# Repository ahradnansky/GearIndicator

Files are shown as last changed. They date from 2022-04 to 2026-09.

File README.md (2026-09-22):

# GearIndicator

Gear Indicator for Kawasaki and Suzuki bikes using communication with ECU over ISO9141 / K-Bus protocol

This project I implemented couple of years ago. We bought Kawasaki Z750 that time and needed to have gear indication
which apparently Kawasaki didn't have installed. About 30 of these were installed on different Kawasaki an Suzuki bikes
in following years. Just dont want this project to throw away and forget. Maybe someone will like it.

## Resources

Project has hardware and software part. Content of Resources directory:

### &emsp;__Eagle

&emsp;Hardware scheme and PCB created in CadSoft Eagle (Autodek Eagle now).
&emsp;Indicator has 2 PCBs. DISP - PCB with 7 segment display and Controller. PWR - PCB with voltage regulator and ISO9141 interface IC.

### &emsp;__HWcomponents

&emsp;Datasheets of all HW components used.

### &emsp;__Manuals

&emsp;We have created couple of installation manuals for Kawasaki and Suzuki bikes. Existing PDFs are here.

### &emsp;__SketchUp

&emsp;3D model of the final product. Prepared to be placed to the potting box. Final product with soldered cable was placed into potting box (type and data in _HWcomponents folder).
&emsp;Then Araldite expoxy was used for potting. Here you will find PCB 3D model as well as 3D model of the completed device.

# Source code

&emsp;Source code in C. Design is based on ATmega328p controller. Atmel Studio (Microchip Studio now) was used as a development IDE at the begining. Later transfeter to PlatformIO - as it is now.

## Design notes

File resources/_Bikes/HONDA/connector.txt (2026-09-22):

HONDA CT - DLC PINOUT (female)
 ---------
|  1 | 2  |-
|            | tab
|  3 | 4  |-
 ---------

1-Brown > SCS (can jumper to Ground to obtain error codes(not tested))
2-Green > Ground (0V)
3-Black/white > Batt (+12V)
4-Orange/White > K-line

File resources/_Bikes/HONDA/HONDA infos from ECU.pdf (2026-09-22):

# CTX-OBD Using a Raspberry-Pi to extract information from a Honda CTX-700

ECU.

February 2016

Here is the Raspberry-Pi mounted on the bike:

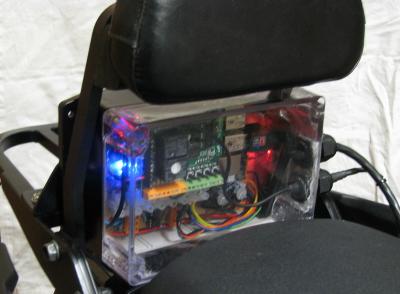
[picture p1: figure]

The data is shown on a character display on the dash. It contains the following information:

Top row: gear position, coolant temp, instantaneous fuel economy (km/litre), fuel in tank
Bottom row: % of chain oiler cycle time, average fuel economy, km to empty.

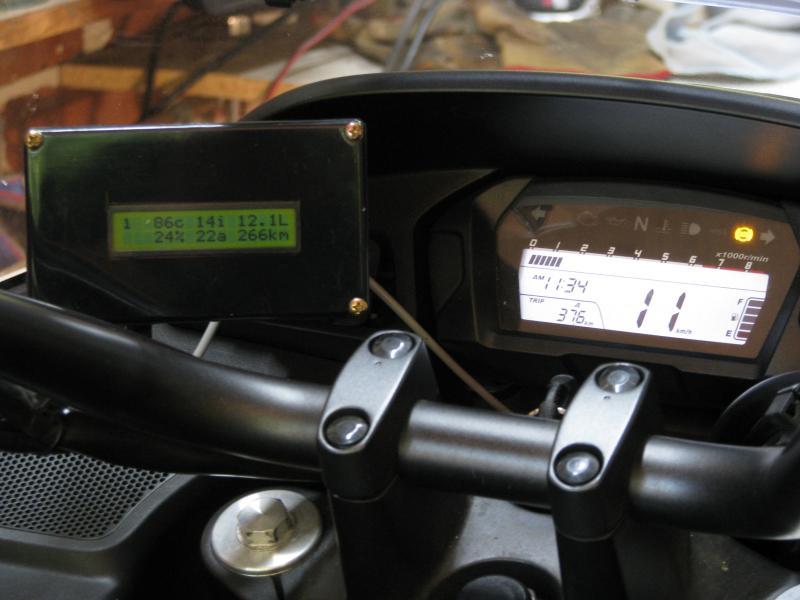
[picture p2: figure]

There is a detailed web interface that can be accessed via a smartphone:

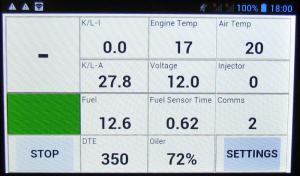
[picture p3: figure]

This document was written to help others to build a system to communicate with the ECU on Honda motorcycles. The vast majority of information here has been obtained from contributors on the pgmfi.org forum. That forum has been “down” for months, so the information is not accessible. Hence this document. Note: Feb 2016 – pgmfi.org is back up!

The key steps to extract information from the ECU are:

1. Make a cable to connect to the ECU diagnostics socket

2. Make an interface board to isolate the 12V bike signals from the 5V computer comms
3. Set up serial communications at 10400baud. This is a non-standard baud rate, so you can’t use a normal USB to serial adapter, and you can’t use a standard automotive ELM327-based unit because the ELM unit calculates the checksum differently and adds it automatically whether you want it to or not.
4. Use the correct message protocol. Honda does not use the standard ISO-9141-2 protocol.
5. Use the correct initialisation sequence. Honda does not use the standard ISO initialisation sequence (another reason not to use an ELM unit)
6. Determine where the data you are looking for is located in the ECU memory. There are a few standard locations, but you may have to proceed to step 7 to test other locations if the standard ones don’t work.
7. Write a program for your computer/Arduino/whatever to get the data and do with it what you will.
8. Package it all into something that fits on your bike.

My setup was based on a Raspberry-Pi model B+ with a PiFace2 I/O board running Raspian. I used a PiFace board because I wanted I/O for driving various things on the bike eg: an auto chain oiler. However, I also used it for pulling the K-line low (see section 5 below). You could use some other method for this function, but it was convenient for me to use one of the PiFace’s relays.

The information flows in my system are quite complex:

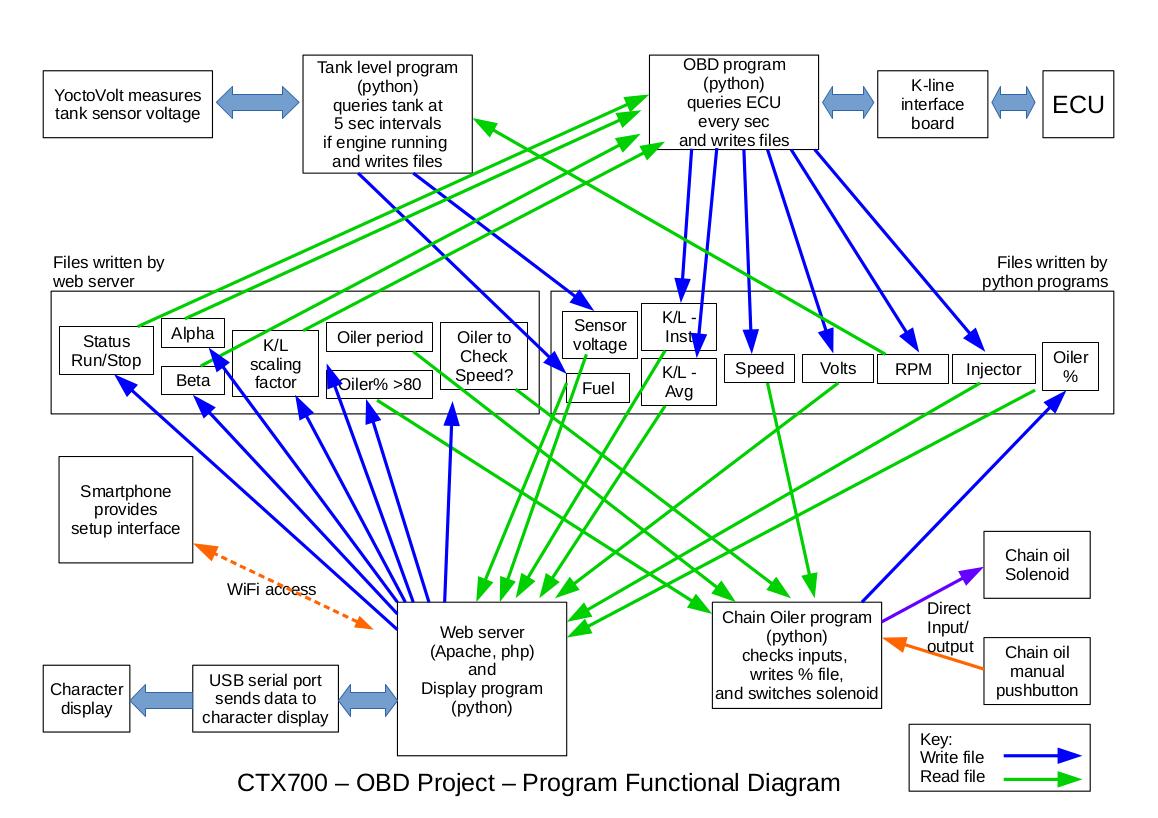
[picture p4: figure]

Going through these items one by one:

## 1. Make a cable

You need to locate the socket on your bike. The CTX socket is a red 4-pin unit near the battery. The connections are 12V, earth, bi-directional K-line and a reset line. You need only the first three to talk to the ECU. Check your manual for the wire colours. The CTX uses a Sumitomo HM090 connector. The connector on the bike looks like this:

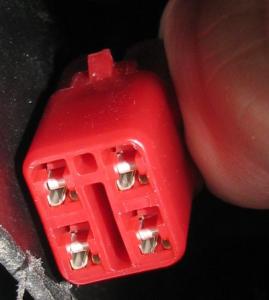
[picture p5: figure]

## 2. Make an Interface Board

I made the following board:

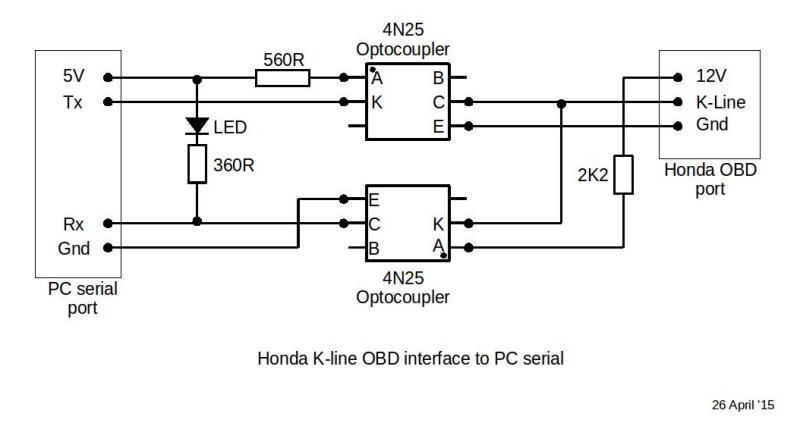
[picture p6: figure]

The K-line rides high (12V) at rest.

I used the above design incorporating optocouplers so that the bike12V was completely isolated from the computer serial adapter. It is possible to use other transistor-based circuits, but you don’t get the same level of isolation.

## 3. Set up Serial Comms

I used a FT232RL USB to serial converter, because it has a base frequency which is able to be scaled down to the 10400baud needed. When plugged into the USB port on the Rpi, it comes up as /dev/ttyUSB0.

To configure the port for 10400baud:

#!/bin/bash

setserial -v /dev/ttyUSB0 spd_cust divisor 2307

This sets the port so that, when you use a program (eg Python) to specify 38400baud for the port, it goes to the custom speed instead of 38400. The port settings are 8 bits, no parity, one stop bit.

To get the adapter to work properly on a R-Pi, you need to add the following in the /boot/cmdline.txt file :

dwc_otg.speed=1

## 4. Use the Correct Message Protocol

Basically the ECU simply responds to requests for information. It doesn’t care if the response is not heard.

A typical request is of the form:

72 07 72 11 00 14 F0 (in hexadecimal)

72: the destination code (I think?)

07: the number of characters in the message including the checksum

72: the type of query (“give me data from memory?”)

11: the data table number

00: the starting register within data table 11

14: the finishing register within data table 11

F0: the checksum

The ECU will respond with a similar format:

02 1A 72 11 00 XX XX XX …XX YY

02: the destination code (I think?)

1A: the number of characters in the message (in this case 26 decimal)

72: the type of query (“data from memory?”)

11: the data table number

00: the starting register

XX: the data

YY: the checksum

The checksum is calculated differently to the ISO OBDII protocol. It goes like this:

Sum all the values of the characters together, and take that value from 100 (hex). If the sum is greater than 100 hex, just use the last two characters (in hex).

So, the request message above (in hex) would be:

0x72 + 0x07 + 0x72 + 0x11 + 0x00 + 0x14 = 0x110

Use only the last two characters, 0x10

0x100 – 0x10 = 0xF0 = the checksum F0

The response checksum is calculated similarly.

There are other query types (the third character in the request sequence). The ones I know to exist are 71, 72, 73 and 74. Code 71 requests all off the table data, rather than a subset:

72 05 71 00 18 requests all of the data in table 00

I don’t know what a code 73 or 74 request does.

## 5. Use the correct Initialisation Sequence

The ECU will not respond until it has received the correct initialisation sequence. I used this:

- Pull the K-line low for 70msec
- Return the K-line to the high state for 120msec
- Send “Wakeup” message: FE 04 FF FF. No response is expected
- Wait 200msec
- Send “Initialise” message: 72 05 00 F0 99
- The ECU should respond with: 02 04 00 FA

That’s it. You can then send requests and the ECU should respond with the data requested. The communications needs to be “kept alive”, however. That means that if the ECU hasn’t received a request within a certain time it goes back to sleep and needs to be initialised again. I think the time is around 3 sec.

Note that I haven’t tested the above times to see what the limits are. All I know is that they work for me and my system.

How do you pull the K-line low? I used a relay driven by the R-Pi. It simply shorted the K-line and ground terminals on the interface board. It doesn’t have to be a relay. If you’re using a “soft serial” where you can directly control the Tx line, you can simply pull that low, and the interface board will pull the K-line low.

## 6. Determine where the data is located

I tabulated the information obtained from a few guys working on this project at pgmfi.org . The data for the small selection of bikes shows that the critical information is held in only a few data table, and some of these tables are duplicated (don’t know why). The most frequently used tables are 00, 10 and 60, 11 and 61, so those the re best places to start. Refer to the “Honda Data Tables.pdf” document:

Honda-data-tables

The document shows the contents of the various tables on the bikes tested, and it shows how to calculate the real life data from the values that come from the ECU.

The data comes in single or double bytes – double bytes are used for data that needs more precision or has a high value (eg: engine speed)

If these data tables don’t work for you, you’ll have to write a program to “scan” through the various table numbers to see where the data exists. The ECU will simply reflect your query back at you if the table doesn’t exist.

## 7. Write a program

Writing a program is up to you. I used Python running under Raspbian. You need a program that handles serial comms (obviously). You will have to be able to handle the following:

- Initialisation
- sending/receiving data normally
- determining if the received data is valid (checksum)
- handling comms errors (the bike is an electrically noisy place)
- keeping the ECU awake, and waking it if it goes to sleep

Receiving data is tricky. Because all the comms come on one line, the serial adapter receives all the data it sends, as well as the responses from the ECU. In addition, the ECU doesn’t necessarily respond immediately – it may be busy doing something else, so you have to wait until you have received the full response. In addition, the program has to ignore anything that comes back from the initialisation sequence.

I used the following process:

1. clear send buffer
2. send message
3. clear receive buffer
4. loop through a single character receive program until a response of the required length has been received (I know how long the response should be)
5. if no new characters are received within x cycles, exit the loop
6. determine if the message is valid – if not, don’t process, and try sending again. If a valid message is not received in x tries, reinitialise the comms.
7. process the valid response

## 8. Package it

This is what I did – it may give you ideas. The R-Pi controls the following:

- The OBD communication
- The auto chain oiler solenoid
- The fuel tank level reporting
- The web server which provides the user interface

My R-Pi was set up as a wireless hotspot so the user interface (an old Medion smartphone) could be used without wires. In addition, it means that any program changes can be done without connecting a keyboard and monitor to the computer.

Here’s the assembly on the test bench:

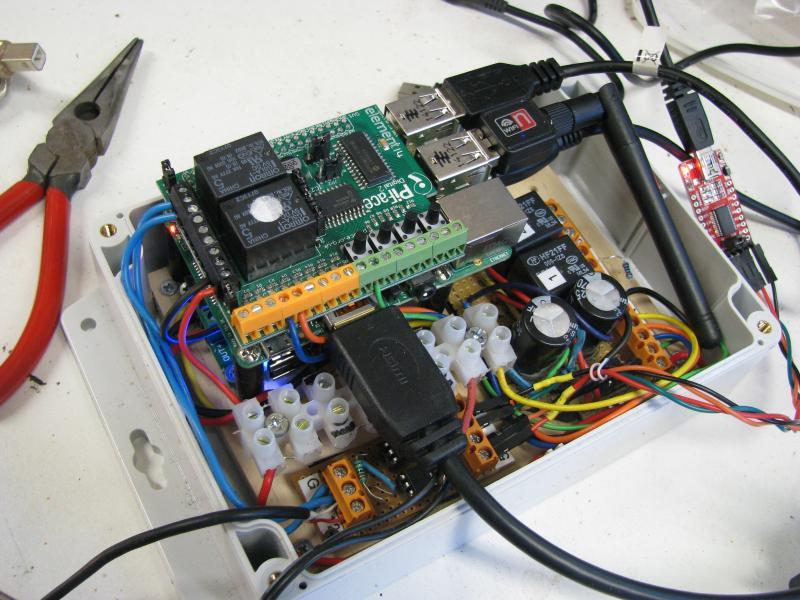
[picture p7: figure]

Here’s the wiring diagram:

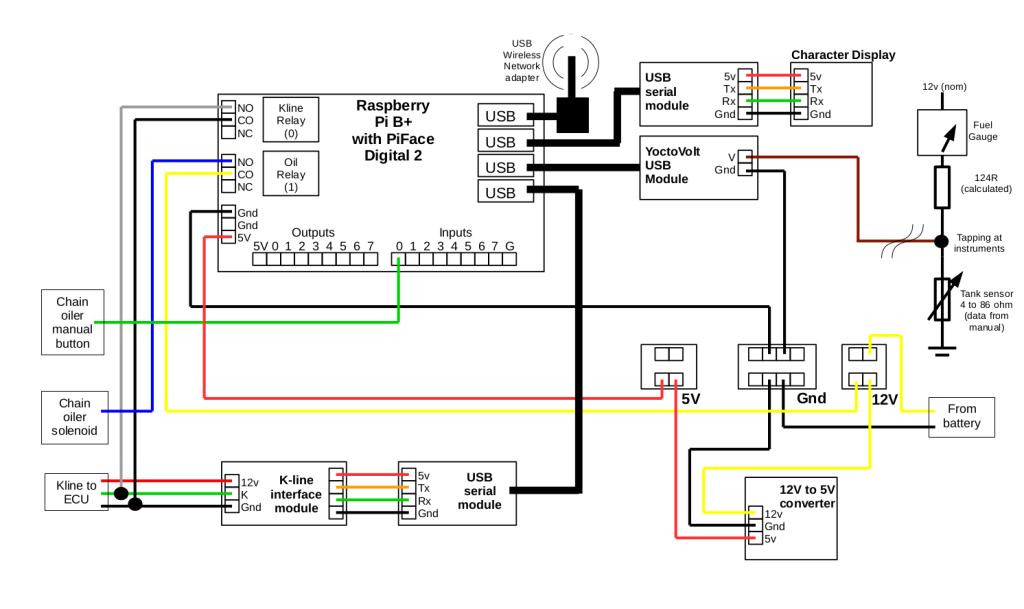
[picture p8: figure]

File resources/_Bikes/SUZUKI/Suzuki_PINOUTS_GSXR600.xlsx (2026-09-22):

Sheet: GSXR600
 |  | 2001-2003 GSXR600 |  |  | 2004-2005 GSXR600 |  |  | 2006-2007 GSXR600 |  |  | 2008-2011 GSXR600
PIN | COLOUR | FUNCTION | PIN | COLOUR | FUNCTION | PIN | COLOUR | FUNCTION | PIN | COLOUR | FUNCTION
1 | WHITE/BLUE | COIL 1 | 1 | W/B | STVA signal (STVA. 2A) | 1 | W/B | STVA signal (STVA. 2A) | 1 | B/R | EXCVA power (MO+)
2 | BLACK | COIL 2 | 2 | P/W | STVA signal (STVA. 1A) | 2 | P/W | STVA signal (STVA. 1A) | 2 | P | Speed sensor signal
3 | YELLOW | COIL 3 | 3 |  |  | 3 | R/B | EXCVA power (MO-) | 3 | W/B | STVA signal (STVA. 2A)
4 | GRAY/WHITE | INJ 4 | 4 |  |  | 4 | B/R | EXCVA power (MO+) | 4 | P/W | STVA signal (STVA. 1A)
5 | GRAY/BLACK | INJ 3 | 5 |  |  | 5 | Y | EXCVA position sensor (MPS) | 5 | B/W
6 | GRAY/YELLOW | INJ 2 | 6 | B/G | Serial data for speedometer | 6 | B/G | Serial data for speedometer | 6 | P/B | TP sensor signal (TP)
7 | GRAY/RED | INJ 1 | 7 |  | TX | 7 | W | TX | 7 | R | Power source for sensors (VCC)
8 |  |  | 8 | P/B | TP sensor signal (TP) | 8 | P/B | TP sensor signal (TP) | 8 | B/Y | CMP sensor signal (CMP+)
9 | YELLOW/BLACK | FUEL PUMP | 9 | G/B | IAP sensor signal (IAP) | 9 | G/B | IAP sensor signal (IAP) | 9 | G/W | CKP sensor signal (CKP+)
10 | GREEN | COIL 4 | 10 | B/BL | ECT sensor signal (ECT) | 10 | B/BL | ECT sensor signal (ECT) | 10 | R/BL | Power source for back-up
11 |  |  | 11 | R | Power source for sensors (VCC) | 11 | R | Power source for sensors (VCC) | 11 | Y/BL | Tachometer
12 |  |  | 12 |  | Blank | 12 | W/G | HO2 sensor signal (OX) [E02,E19,E24] | 12 | O/G | Power source
13 |  |  | 13 | B/Y | CMP sensor signal (CMP+) | 13 | B/Y | CMP sensor signal (CMP+) | 13 | R/B | EXCVA power (MO-)
14 |  |  | 14 | G/W | CKP sensor signal (CKP+) | 14 | G/W | CKP sensor signal (CKP+) | 14 | Y | EXCVA position sensor (MPS)
15 | BLUE/RED | MAP SELECT | 15 |  | Blank | 15 | Bl/R | Blank | 15 | BL/Y
16 | BLUE/YELLOW | COS2 | 16 | R/BL | Power source for back-up | 16 | R/BL | Power source for back-up | 16 | BL/G
17 | ORANGE/WHITE | SWITCHED 12V | 17 | O/G | Power source | 17 | O/G | Power source | 17
18 | BLACK/WHITE | GROUND | 18 | G | STVA signal (STVA. 2B) | 18 | G | STVA signal (STVA. 2B) | 18 | Y/W | STP sensor signal (STP)
19 | BLACK/YELLOW | STARTER RELAY INPUT | 19 | B/LG | STVA signal (STVA. 1B) | 19 | B/LG | STVA signal (STVA. 1B) | 19 | G/B | IAP sensor signal (IAP)
20 | BLUE | NEUTRAL INPUT | 20 | Y/W | STP sensor signal (STP) | 20 | Y/W | STP sensor signal (STP) | 20 | G/Y | AP sensor signal (AP)
21 | BLACK/BROWN | GROUND | 21 | O/Y | Ignition switch signal [E03,E28,E33] | 21 | Br/Y | Ignition switch signal [E03,E28,E33] | 21 | G/BL | CKP sensor signal (CKPS-)
22 | WHITE/RED | DEALER MODE SWITCH | 22 | B | TO sensor signal (TOS) | 22 | B | TO sensor signal (TOS) | 22 | P | GP switch signal (GP)
23 | BLUE/WHITE | COV1 | 23 | P | GP switch signal (GP) | 23 | P | GP switch signal (GP) | 23 | B/G | Serial data for speedometer
24 | BLUE/BLACK | COV2 | 24 |  | RX | 24 | DGR | RX | 24 | Y/R | Power source for fuel injector (VM)
25 | BLUE/GREEN | COV3 | 25 |  | Blank | 25 |  | Reset | 25 | BR | Steering Damper solenoid (SSO-)
26 | BLACK/WHITE | GROUND | 26 | G/Y | AP sensor signal (AP) | 26 | G/Y | AP sensor signal (AP) | 26 | W | Steering Damper solenoid (SSO+)
27 | BLACK/WHITE | GROUND | 27 | DG | IAT sensor signal (IAT) | 27 | DG | IAT sensor signal (IAT) | 27 | G | STVA signal (STVA. 2B)
28 | YELLOW/GREEN | STARTER RELAY POWER | 28 |  | FWE | 28 |  | FWE | 28 | B/LG | STVA signal (STVA. 1B)
29 |  |  | 29 | B/BR | Sensors ground (E2) | 29 | B/BR | Sensors ground (E2) | 29
30 |  |  | 30 | BR | CMP sensor signal (CMP-) | 30 | B/BR | EXCVA & HO2 sensor control selector [For E02,E19] | 30
31 | BROWN | PIN 5 2ND ECU | 31 | G/BL | CKP sensor signal (CKP-) | 31 | O/BL | CKP sensor signal (CKP-) | 31 | B | TO sensor signal (TOS)
32 |  |  | 32 | GR | Serial data for self-diagnosis (K-Line) | 32 | GR | Serial data for self-diagnosis (K-Line) | 32 | B/BL | ECT sensor signal (ECT)
33 |  |  | 33 | Y/R | Power source for fuel injector (VM) | 33 | Y/R | Power source for fuel injector (VM) | 33 | DG | IAT sensor signal (IAT)
34 |  |  | 34 | B/W | ECM ground (E1) | 34 | B/W | ECM ground (E1) | 34 | W/G | HO2 sensor (HO2S)
35 | BLACK/WHITE | GROUND | 35 | BL/Y |  | 35 |  |  | 35 | B/BR | Sensors ground (E2)
36 | WHITE | CRANK + | 36 | BL/R |  | 36 |  |  | 36 | B/W | ECM ground (E1)
37 | BLACK/YELLOW | CAM + | 37 | Y/BL | Tachometer | 37 | BL/Y |  | 37 | G | ISC valve signal (ISC 2A)
38 |  |  | 38 |  |  | 38 | Y/BL | Tachometer | 38 | Y | ISC valve signal (ISC 1B)
39 |  |  | 39 | Y/B | Fuel pump relay (FP Relay) | 39 | Y/B | Fuel pump relay (FP Relay) | 39 | BL | ISC valve signal (ISC 1A)
40 |  |  | 40 | Y/G | Starter relay | 40 | R/Y | Immobilizer communication [E02,E19,E24] | 40 | Y/B | Fuel pump relay (FP Relay)
41 |  |  | 41 | GR/R | Primary fuel injector #4 (#41) | 41 | W/B | HO2 Sensor Heater (OXH) [For E02,E19] | 41 | W/B | HO2 sensor heater (HO2H)
42 | YELLOW/RED | FUEL 12V | 42 | GR/Y | Primary fuel injector #3 (#31) | 42 | Y/G | Starter relay | 42 | G/R | Cooling fan relay (FAR)
43 | GREEN/WHITE | CRANK - | 43 | GR/B | Primary fuel injector #2 (#21) | 43 | O/R | Cooling fan relay (FAR) | 43 | GR/R | Primary fuel injector #4 (#41)
44 | BROWN | CAM - | 44 | GR/W | Primary fuel injector #1 (#11) | 44 | W/G | PAIR control solenoid valve (PAIR) | 44 | GR/Y | Primary fuel injector #3 (#31)
45 |  |  | 45 | Y | Ignition coil #3 | 45 | GR/R | Primary fuel injector #4 (#41) | 45 | GR/B | Primary fuel injector #2 (#21)
46 |  |  | 46 | B | Ignition coil #2 | 46 | GR/Y | Primary fuel injector #3 (#31) | 46 | GR/W | Primary fuel injector #1 (#11)
47 |  |  | 47 | W/BL | Ignition coil #1 | 47 | GR/B | Primary fuel injector #2 (#21) | 47 | B | Ignition coil #2
48 | RED | VCC | 48 | BL/G |  | 48 | GR/W | Primary fuel injector #1 (#11) | 48 | W/BL | Ignition coil #1
49 | PINK/BLACK | TPS | 49 | BL/B |  | 49 | Y | Ignition coil #3 | 49 | BR | ISC valve signal (ISC 2B)
50 | DARK GREEN | AIR TEMP | 50 | B/W |  | 50 | B | Ignition coil #2 | 50 | O/R | Driving mode switch 2 (DMS2)
51 | BLACK/BLUE | WATER TEMP | 51 | W/R |  | 51 | W/BL | Ignition coil #1 | 51 | BL/B
52 | GREEN/YELLOW | AP SENSOR | 52 | B/W |  | 52 |  |  | 52 | BL/W
53 |  |  | 53 | BL |  | 53 |  |  | 53 | R/Y | Immobilizer communication [E2,E19,E24]
54 | BLACK/BROWN | SENSOR GROUND | 54 | BL | Neutral switch | 54 | BL/G |  | 54 | Y/G | Starter relay
55 | YELLOW/BLU | TACH OUT | 55 | B/Y | Clutch position switch | 55 | BL/B |  | 55 | W/G | PAIR control solenoid valve (PAIR)
56 | BLACK/GREEN | tech | 56 | W/G | PAIR control solenoid valve (PAIR) | 56 | BL/W |  | 56 | LG/BL | Secondary fuel injector #4 (#42)
57 | PINK | GEAR POSITION | 57 | BLACK/WHITE | Ground | 57 | O/BL | Immobilizer communication [E02,E19,E24] | 57 | LG/G | Secondary fuel injector #3 (#32)
58 | GREEN/BLACK | IAPS | 58 | BLACK/WHITE | Ground | 58 | B/BR | Map Switch [Mode Select Switch] | 58 | LG/W | Secondary fuel injector #2 (#22)
59 | BLACK | TIP OVER | 59 | BLACK/WHITE | Ground for ignition system | 59 | BL | Neutral switch | 59 | LG | Secondary fuel injector #1 (#12)
60 | ORANGE/YELLOW | ANTI THEFT | 60 | GREEN | Ignition coil #4 | 60 | B/Y | Clutch position switch | 60 | Y | Ignition coil #3
 | SECONDARY THROTTLE ECU |  |  |  | YOSHI CONNECTOR | 61 | LG/BL | Secondary fuel injector #4 (#42) | 61 |  | EVAP system purge control solenoid [E33]
1 | LIGHT BLUE | ST PS +5V | 1 |  |  | 62 | LG/G | Secondary fuel injector #3 (#32) | 62 | GR | Serial data for self-diagnosis
2 | BLACK | ST PS GND | 2 | R | PIN 11 (VCC) | 63 | LG/W | Secondary fuel injector #2 (#22) | 63 | O/BL | Driving mode switch 1 (DMS1)
3 | BLACK/GRAY | GND | 3 | BL/Y | PIN 35 | 64 | LG | Secondary fuel injector #1 (#12) | 64 | BR/Y | Immobilizer indicator light [E02,E19,E24]
4 | ORANGE/WHITE | 12V | 4 | BL/R | PIN 36 | 65 | W/R | Dealer Mode | 65 | O/BL | Immobilizer communication [E2,E19,E24]
5 | BROWN | PIN31 ECU | 5 | BL/G | PIN 48 | 66 | B/W | General ground (E01) | 66 | B/W
6 | YELLOW | ST PS INPUT | 6 | BL/B | PIN 49 | 67 | B/W | Ground for ignition system (E03) | 67 | BL | Neutral switch
7 | RED/BLACK | M- | 7 | BL/W | PIN 50 | 68 | G | Ignition coil #4 | 68 | B/W | General ground (E1)
8 | YELLOW/BLACK | M+ | 8 | B/BR | PIN 29 |  | SDS |  | 69 | B/Y | Clutch position switch
 |  |  |  |  |  | 1 | B/W | PIN 34 GND | 70 | W/R | Mode select switch
 |  |  |  |  |  | 2 | GR | PIN 32 (KLINE) | 71 | B/W | Ground for ignition system
 |  |  |  |  |  | 3 | DGR | PIN 24 (RX) | 72 | G | Ignition coil #4
 |  |  |  |  |  | 4 | W/R | PIN 56 Dealer Mode |  | SDS
 |  |  |  |  |  | 5 | W | PIN 7 (TX) | 1 | B/W | PIN 36
 |  |  |  |  |  | 6 | O/G | PIN 17 (PWR SOURCE) +12V | 2 | GR | PIN 62 (KLINE)
 |  |  |  |  |  |  |  | YOSHI CONNECTOR | 3
 |  |  |  |  |  | 1 |  |  | 4 | W/R | PIN 70
 |  |  |  |  |  | 2 | R | PIN 11 (VCC) | 5
 |  |  |  |  |  | 3 | BL/Y | PIN 37 | 6 | O/G | PIN 12 (PWR SOURCE)
 |  |  |  |  |  | 4 | BL/R | PIN 15 |  |  | YOSHI CONNECTOR
 |  |  |  |  |  | 5 | BL/G | PIN 54 | 1
 |  |  |  |  |  | 6 | BL/B | PIN 55 | 2 | R | PIN 7 (VCC)
 |  |  |  |  |  | 7 | BL/W | PIN 56 | 3 | BL/Y | PIN 15
 |  |  |  |  |  | 8 | B/BR | PIN 29 | 4
 |  |  |  |  |  |  |  |  | 5 | BL/G | PIN 16
 |  |  |  |  |  |  |  |  | 6 | BL/B | PIN 51
 |  |  |  |  |  |  |  |  | 7 | BL/W | PIN 52
 |  |  |  |  |  |  |  |  | 8 | B/BR | PIN 35
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

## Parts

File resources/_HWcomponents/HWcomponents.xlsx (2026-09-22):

Component | Type | Pcs | unit
Controller | ATMEGA328P | 1 | off
Cer. resonator | ZTTCR8.00MG | 1 | off
Resistor | 470R, 0603, 0.25W | 8 | off
Capacitor | Tantal 10u/25V Case A | 1 | off
Capacitor | Tantal 22u/10V Case A | 1 | off
Capacitor | 100n, 50V, 1206 | 1 | off
Bus Driver | L9637 | 1 | off
Volt. Regulator | AP1117E50 | 1 | off
Resitor | 560R, 1206, 0.25W | 1 | off
Diode | DIODE S1M, 1A, 1kV | 1 | off
7-segment LED | 7SEG SA56-11LSRWA (RED) | 1 | off
Potting box | HAMMOND 1596B102-10 ENCLOSURE, POTTING BOX, ABS, BLACK | 1 | off
Cable | Helukabel TRONIC (LiYY) 18002, 3 x 0.14mm2 | 2 | m
Potting expoxy | Araldite2020 (clear epoxy adhesive system) | 9 | ml

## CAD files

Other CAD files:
resources/_SketchUp/GearIndicator_pcb.skp
resources/_SketchUp/GearIndicator_pcb_model.skp

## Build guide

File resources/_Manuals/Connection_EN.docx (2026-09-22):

Gear Indicator connection to a Kawasaki service connector

1. Find service connector

99% Kawasaki bikes have service connector under the passenger seat. Type of the connector or its shape and color can be different in comparison with the one on the photo (Z750 -2008). Common feature of the connector: it is possible to push 4 into it.

2. Remove the connector protector

On the top of service connector is the protector. Remove it and save it for future use if necessary.

3. Connection

Connect indicator pins into service connector as displayed on the photo below.

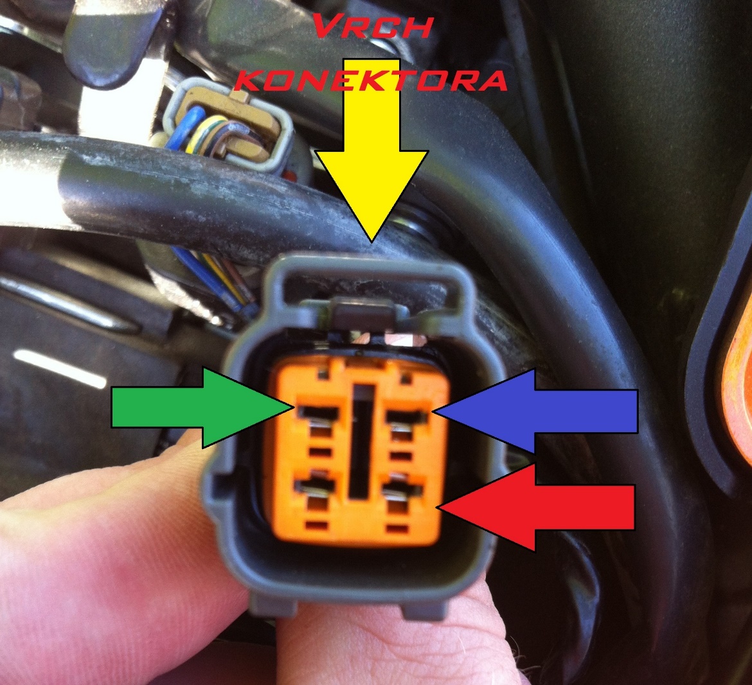
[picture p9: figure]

TOP OF THE CONNECTOR

KBUS`

GND

+12V

4. Proper insulation

After correct connection of all pins into service connector ii necessary to proper insulate everything by PVC tape to avoid shortcut or contact with water.

Note:

In case of accidental short cut during the installation the protecting fuse of the service connector can be blown. It is recommended to lead the cable smoothly without sharp angles and avoid contact with hot parts of the bike’s engine.

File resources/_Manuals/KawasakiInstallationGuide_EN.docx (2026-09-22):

Gear indication installation guide for Kawasaki bikes

1. Turn off ignition to prevent accidental protecting fuse blow during installation. (Better scenario would be additional work to change the fuse).
2. Install the indicator to a suitable place Select suitable place for installation to be visible during riding the bike. Ideal place is just beside the speedometer on the smooth plastic or metallic surface. Use degreasing agent to properly clean the surface. Remove the foil from the adhesive tape at the bottom of the indicator and place it to a desired location. Press and hold for about 10s (according to recommendation of 3M double-sided adhesive tape manufacturer).
3. Find the service (diagnostic) connector

99% Kawasaki bikes have service connector under the passenger seat. Connector color can be various – grey, black, or transparent but it is always 4-pin connector.

4. Fix the indicator cable Indicator cable should be routed together with other bike cables up to the service connector. Don’t stretch the cable nor do sharp bends. Keep minimum radius 20mm. In case of installation to handlebars or any other movable part allow free cable move. Fix cable at multiple places by using plastic ties and route it up to service connector.

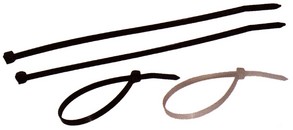
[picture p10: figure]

Avoid cable contact with hot parts of the engine to prevent its damage by heat.

5. Remove service connector protector

Service connector can be equipped by protector. Remove it and save in case the indicator will be uninstalled in the future. The protector can look like this:

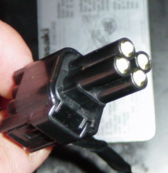
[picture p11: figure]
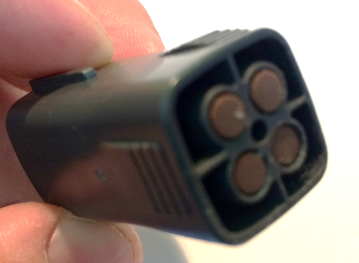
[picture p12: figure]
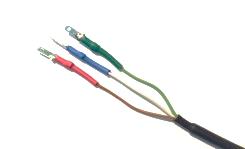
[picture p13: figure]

6. Connect indicator cable to connector

Cable is ended by 3 colored wires – red, blue and green. Connect these wires as displayed on the picture below:

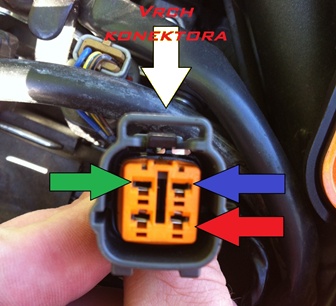
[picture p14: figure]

7. Turn-on ignition Indicator will show welcome message “LEtS ridE“ and consequently displays numbers from 0 to 6 and back 6 to 0. Then indicator starts to communicate to bike control unit (ECU). In case of correct installation and neutral gear set (even without running engine) should indicator show ‘0’ (neutral) or ‘-‘.

In case indicator showing ‘-‘ character together with ‘.’

it means indicator is not communicating to ECU. Check the connection again.

8. Insulate and protect the connector with PVC tape

Turn-off ignition again. Insulate the connector by using PVC tape and fix wires inside the connector properly to avoid disconnection by vibrations. PVC tape also protects connector against water.

„ShiftLight“ function setup – RPM over limit indication

WARNING !

Pre-condition for the setup of this function is fully functional gear indication on your bike. If your gear indication works correctly, you can start „ShiftLight“ function setup.

Before the setup it is recommended to heat-up the engine to operation temperature to avoid negative impact of high RPM on the cold engine.

1. Turn-off ignition.
2. Disconnect green wire from the service connector. Rest of wires (red and blue) leave connected.
3. Connect Green wire to the ground (- pole). Ideally connect Green and Blue wires together at the point of Blue wire connection to service connector. (It is enough to connect metal part of Green wire metal part with Blue wire metal part and hold it by hand).
4. Turn-on ignition. Indicator will show “LEtS rIdE 1-2-3-4-5-6-5-4-2-1”. Wait 2-3 seconds until indicator shows ‘P’. That indicates that ShiftLight function setup mode is active.
5. Turn-off ignition.
6. Connect Green wire back to service connector.

CONNECTOR TOP

7. Turn-on ignition and start the engine immediately. Wait until indicator shows ‘P’. It indicates that ShiftLight function setup mode is active.
8. Increase RPM to desired limit (>2000 RPM) and keep it for 3-4 seconds. ‘P’ displayed on the indicator will start blinking which indicates that RMP limit value was correctly stored to the memory.
9. Turn-off ignition immediately to finish ShiftLight function setup correctly.
10. Insulate the indicator’s connector by using PVC tape and fix wires inside the connector properly to avoid disconnection by vibrations. PVC tape also protects connector against water.

Set Gear Indicator to default setting (without ShiftLight function)

1. Follow steps 1 to 5 of „ShiftLight“ function setup – RPM over limit indication.
2. Leave Green wire disconnected from the service connector. Ensure that Green wire is air-gapped from any other part of the bike.
3. Turn-on ignition and wait until indicator displays ‘P’.
4. Wait another ~10 seconds until indicator displays ‘-‘ together with dot ‘.’
5. Now is the Gear Indicator in default state (without ShiftLight function).
6. Turn-off ignition.
7. Connect Green wire back to service connector.
8. Insulate the indicator’s connector by using PVC tape and fix wires inside the connector properly to avoid disconnection by vibrations. PVC tape also protects connector against water.

Installation Guide EN, v3.0/KAWA 3/2016 Page 1/2

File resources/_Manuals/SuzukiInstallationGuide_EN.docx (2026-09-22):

Gear indication installation guide for Suzuki bikes

1. Turn off ignition to prevent accidental protecting fuse blow during installation. (Better scenario would be additional work to change the fuse).
2. Install the indicator to a suitable place Select suitable place for installation to be visible during riding the bike. Ideal place is just beside the speedometer on the smooth plastic or metallic surface. Use degreasing agent to properly clean the surface. Remove the foil from the adhesive tape at the bottom of the indicator and place it to a desired location. Press and hold for about 10s (according to recommendation of 3M double-sided adhesive tape manufacturer).
3. Find the service (diagnostic) connector

Suzuki V-Strom bikes have service connector under the seat. Volusia (as well as Marauder) have it under the right cover next to the seat. Connector color is usually white. It is always 6-pin connector.

4. Fix the indicator cable Indicator cable should be routed together with other bike cables up to the service connector. Don’t stretch the cable nor do sharp bends. Keep minimum radius 20mm. In case of installation to handlebars or any other movable part allow free cable move. Fix cable at multiple places by using plastic ties and route it up to service connector.


Avoid cable contact with hot parts of the engine to prevent its damage by heat.

5. Remove service connector protector

Service connector can be equipped by protector. Remove it and save in case the indicator will be uninstalled in the future. The protector can look like this:

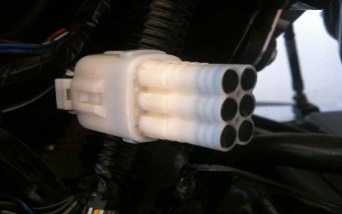
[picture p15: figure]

6. Connect indicator cable to connector

Cable is ended by 3 colored wires – red, blue and green. Connect these wires as displayed on the picture below:

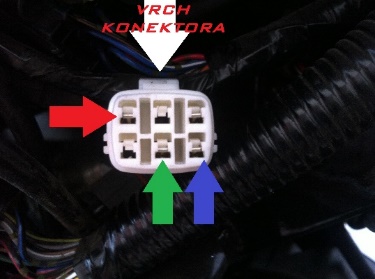
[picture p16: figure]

CONNECTOR TOP

7. Turn-on ignition Indicator will show welcome message “LEtS ridE“ and consequently displays numbers from 0 to 6 and back 6 to 0. Then indicator starts to communicate to bike control unit (ECU). In case of correct installation and neutral gear set (even without running engine) should indicator show ‘0’ (neutral) or ‘-‘.

In case indicator showing ‘-‘ character together with ‘.’

it means indicator is not communicating to ECU. Check the connection again.

8. Insulate and protect the connector with PVC tape

Turn-off ignition again. Insulate the connector by using PVC tape and fix wires inside the connector properly to avoid disconnection by vibrations. PVC tape also protects connector against water.

„ShiftLight“ function setup – RPM over limit indication

WARNING !

Pre-condition for the setup of this function is fully functional gear indication on your bike. If your gear indication works correctly, you can start „ShiftLight“ function setup.

Before the setup it is recommended to heat-up the engine to operation temperature to avoid negative impact of high RPM on the cold engine.

1. Turn-off ignition.
2. Disconnect green wire from the service connector. Rest of wires (red and blue) leave connected.
3. Connect Green wire to the ground (- pole). Ideally connect Green and Blue wires together at the point of Blue wire connection to service connector. (It is enough to connect metal part of Green wire metal part with Blue wire metal part and hold it by hand).
4. Turn-on ignition. Indicator will show “LEtS rIdE 1-2-3-4-5-6-5-4-2-1”. Wait 2-3 seconds until indicator shows ‘P’. That indicates that ShiftLight function setup mode is active.
5. Turn-off ignition.
6. Connect Green wire back to service connector.

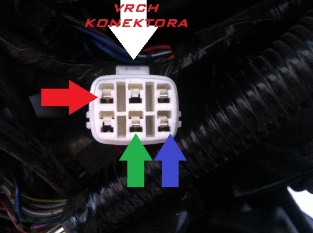
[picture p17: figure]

CONNECTOR TOP

7. Turn-on ignition and start the engine immediately. Wait until indicator shows ‘P’. It indicates that ShiftLight function setup mode is active.
8. Increase RPM to desired limit (>2000 RPM) and keep it for 3-4 seconds. ‘P’ displayed on the indicator will start blinking which indicates that RMP limit value was correctly stored to the memory.
9. Turn-off ignition immediately to finish ShiftLight function setup correctly.
10. Insulate the indicator’s connector by using PVC tape and fix wires inside the connector properly to avoid disconnection by vibrations. PVC tape also protects connector against water.

Set Gear Indicator to default setting (without ShiftLight function)

1. Follow steps 1 to 5 of „ShiftLight“ function setup – RPM over limit indication.
2. Leave Green wire disconnected from the service connector. Ensure that Green wire is air-gapped from any other part of the bike.
3. Turn-on ignition and wait until indicator displays ‘P’.
4. Wait another ~10 seconds until indicator displays ‘-‘ together with dot ‘.’
5. Now is the Gear Indicator in default state (without ShiftLight function).
6. Turn-off ignition.
7. Connect Green wire back to service connector.
8. Insulate the indicator’s connector by using PVC tape and fix wires inside the connector properly to avoid disconnection by vibrations. PVC tape also protects connector against water.

Installation Guide EN, v2.0/SU 3/2016 Page 1/2

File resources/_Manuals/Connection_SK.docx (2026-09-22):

Návod na pripojenie ukazovateľa do diagnostického konektora

1. Nájsť dignostický (servisný) konektor

V 99% motocykloch zn. Kawasaki sa nachádza pod zadnou sedačkou. Prevedenie konektora sa môže líšiť tvarovo aj farebne než je vyobrazené na fotke (Foto typ Z750 -08). Podstatným znakom konektoru je že je doň možné vsunúť 4 piny.

2. Odstránenie upchávky servisného konektoru

Na servisnom konektore sa môže nachádzať záslepka, ktorú je nutné pred pripájaním odstrániť a uschovať pre prípad demontáže ukazovateľa.

3. Pripojenie

Piny ukazovateľa sú farebne rozlíšené a je ich potrebné zapojiť podľa nasledovného obrázku.


KBUS`

GND

+12V

4. Zaizolovanie

Po pripojení pinov do konektoru je nutné celú sústavu (t.j. konektor aj piny) dôkladne obmotať izolačnou páskou aby nedošlo k skratu alebo kontaktu s vodou.

Poznámka: V prípade skratu pri montáži môže dôjsť k prerazeniu ochrannej poistky vedúcej do diagnostického konektora. Kábel neodporúčam zalamovať ani naťahovať.

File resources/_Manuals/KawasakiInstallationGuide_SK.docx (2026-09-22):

Návod na inštaláciu ukazovateľa zaradenej rýchlosti na motocykle Kawasaki

1. Vypnite kľúčik zapaľovania aby počas montáž nedošlo k nežiaducemu skratu a tým prepáleniu ochrannej poistky. (V lepšom prípade práca navyše s výmenou poistky).
2. Upevnite ukazovateľ na vhodnom mieste Miesto inštalácie zvoľte tak, aby bol ukazovateľ dobre viditeľný počas jazdy. Ideálne je umiestnenie vedľa tachometra, na hladkej plastovej, príp. kovovej ploche. Miesto inštalácie odmastite liehom , alebo technickým benzínom. Odstráňte fóliu z lepiacej pásky na spodnej časti ukazovateľa a prilepte ukazovateľ na želané miesto. Pritlačte a podržte na mieste cca. 10s (v súlade s odporúčaním výrobcu lepiacej pásky - 3M).
3. Nájdite diagnostický (servisný) konektor

U 99% motocyklov Kawasaki sa diagnostický konektor (KDS) nachádza pod sedačkou spolujazdca. Farba konektora môže byť šedá, čierna, alebo transparentná. Je to ale vždy 4 pólový konektor.

4. Upevnite kábel vedúci z ukazovateľa Kábel veďte súbežne s ostatnou kabelážou motocykla až k diagnostickému konektoru. Kábel príliš nenapínajte a nezalamujte ho. Dodržujte polomer ohybu minimálne 20mm. V prípade inštalácie ukazovateľa na riadidlá, alebo časť pohybujúcu sa spolu s riadidlami, umožnite jeho voľný pohyb počas otáčania riadidiel. Kábel upevnite na viacerých miestach, najlepšie prostredníctvom plastových sťahovacích pások a priveďte ho postupne až k diagnostickému konektoru.


Vyhnite sa kontaktu kábla s horúcimi časťami motora, aby nedošlo k jeho poškodeniu teplom.

5. Odstráňte chránič servisného konektora

Na servisnom konektore sa môže nachádzať chránič (zaslepenie), ktorý treba pred pripájaním odstrániť a uschovať pre prípad demontáže ukazovateľa. Chránič môže vyzerať takto:


6. Pripojte ukazovateľ do konektora

Kábel vedúci z ukazovateľa je ukončený troma (3) vodičmi, ktoré sú farebne označené – červený, modrý a zelený. Do diagnostického konektora ich zapojte podľa nasledujúceho obrázka:


7. Zapnite zapaľovanie Na ukazovateli sa zobrazí správa „LEtS ridE“ a postupné zobrazenie čísel 0-6 a späť 6-0. Následne začne ukazovateľ komunikovať s riadiacou jednotkou. V prípade správnej montáže by pri zaradenom neutrále (i bez bežiaceho motora) mal ukazovateľ zobrazovať nula ‘0’ (neutrál), prípadne znak pomlčka ‘-‘.

Ak sa na ukazovateli zobrazuje znak pomlčky ‘-‘ spolu so znakom bodka ‘.’:

znamená to, že ukazovateľ nekomunikuje s riadiacou jednotkou. V tomto prípade znovu prekontrolujte správnosť zapojenia.

8. Zaizolujte konektor PVC páskou

Znovu vypnite zapaľovanie. Izolačnou páskou PVC zaizolujte konektor a finálne upevnite vodiče v ňom, aby počas prevádzky nedošlo v dôsledku vibrácií k odpojeniu kábla z konektora. Izolačná páska tiež zabráni prípadnému nežiaducemu vniknutiu vlhkosti do konektora.

Návod na nastavenie funkcie „ShiftLight“ – indikácia prekročenia otáčok motora

POZOR !

Predpokladom na nastavenie tejto funkcie je funkčné zobrazovanie zaradenej rýchlosti na vašom motocykli. Ak vám zobrazovanie zaradenej rýchlosti pracuje korektne, môžete pristúpiť k nastaveniu funkcie ShiftLight.

Pred nastavovaním odporúčame motor zahriať na prevádzkovú teplotu krátkou jazdou, aby sa predišlo negatívnym následkom behu studeného motora na vysokých otáčkach.

1. Vypnite zapaľovanie.
2. Z diagnostického konektora vytiahnite zelený vodič, ostatné vodiče (červený a modrý) nechajte zapojené v diagnostickom konektore.
3. Zelený vodič pripojte na kostru motocykla (mínus pól), ideálne ho spojte s modrým vodičom v mieste pripojenia modrého vodiča do diagnostického konektora motocykla. (Stačí oprieť kovovú časť zeleného vodiča o kovovú časť modrého vodiča a takto to pridržať na mieste rukou).
4. Zapnite zapaľovanie. Na displeji sa zobrazí „LEtS rIdE 1-2-3-4-5-6-5-4-2-1”. Počkajte cca. 2-3 sekundy, pokým sa na displeji nezobrazí „P“ čo indikuje prechod ukazovateľa do režimu nastavenia funkcie ShiftLight.
5. Vypnite zapaľovanie.
6. Zapojte Zelený vodič späť do diagnostického konektora.
7. Zapnite zapaľovanie a ihneď naštartujte motor. Počkajte kým sa na displeji zobrazí „P“ – indikácia, že ukazovateľ je v režime nastavenia funkcie ShiftLight.
8. Zvýšte otáčky motora na požadovanú hodnotu (>2000 RPM) a držte ich cca. 3-4s. „P“ zobrazené na displeji začne blikať čím ukazovateľ oznamuje, že zaznamenal hodnotu otáčok a uložil ju do pamäte.
9. Ihneď vypnite zapaľovanie, aby sa korektne ukončil režim nastavenia funkcie ShiftLight.
10. Izolačnou páskou PVC zaizolujte konektor a finálne upevnite vodiče v ňom, aby počas prevádzky nedošlo v dôsledku vibrácií k odpojeniu kábla z konektora. Izolačná páska tiež zabráni prípadnému nežiaducemu vniknutiu vlhkosti do konektora.

Návod na návrat ukazovateľa do základného stavu (bez nastavenej funkcie ShiftLight)

1. Postupujte podľa krokov 1 až 5 Návodu na nastavenie funkcie ShifLight.
2. Nechajte zelený vodič odpojený z diagnostického konektora tak, aby sa svojou živou (kovovou) časťou nedotýkal žiadnej časti motocykla.
3. Zapnite zapaľovanie, počkajte kým sa na displeji zobrazí „P“.
4. Počkajte ďalších cca. 10s, kým sa na displeji nezobrazí znak pomlčky ‘-‘ spolu so znakom bodka ‘.’
5. Od tohto momentu je ukazovateľ v základnom stave (bez nastavenej funkcie ShiftLight).
6. Vypnite zapaľovanie.
7. Zapojte Zelený vodič späť do diagnostického konektora.
8. Izolačnou páskou PVC zaizolujte konektor a finálne upevnite vodiče v ňom, aby počas prevádzky nedošlo v dôsledku vibrácií k odpojeniu kábla z konektora. Izolačná páska tiež zabráni prípadnému nežiaducemu vniknutiu vlhkosti do konektora.

Inštalačný manuál SK, v3.0/KAWA 3/2016 Strana 1/2

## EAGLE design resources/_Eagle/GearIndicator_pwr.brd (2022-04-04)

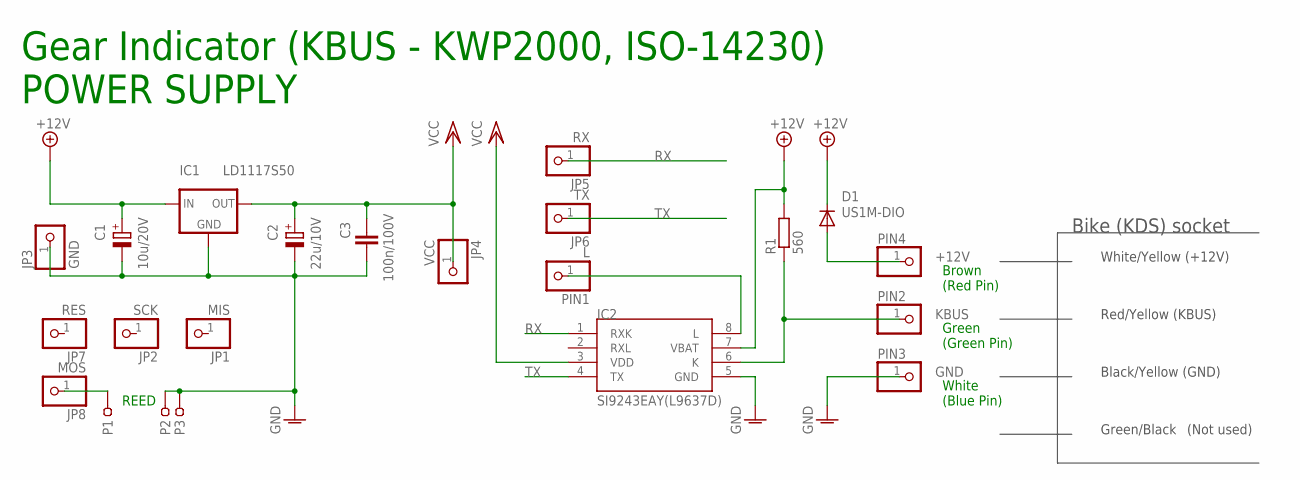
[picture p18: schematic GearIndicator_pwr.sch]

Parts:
C1: 10u/20V; CT3216
C2: 22u/10V; CT3216
C3: 100n/100V; C1206
D1: US1M-DIO; DO-214AC
IC1: LD1117S50; SOT223
IC2: SI9243EAY(L9637D); SO08
JP1: MIS; 1X01
JP2: SCK; 1X01
JP3: GND; 1X01
JP4: VCC; 1X01
JP5: RX; 1X01
JP6: TX; 1X01
JP7: RES; 1X01
JP8: MOS; 1X01
P1, P2, P3: SMD2; SMD_2X1
PIN1: L; PIN1
PIN2: KBUS; PIN1
PIN3: GND; PIN1
PIN4: +12V; PIN1
R1: 560; R1206

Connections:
+12V: C1.+, D1.C, IC1.3 (IN), IC2.7 (VBAT), R1.2
GND: C1.-, C2.-, C3.2, IC1.1 (GND), IC2.5 (GND), JP3.1, P2.P$1, P3.P$1, PIN3.1
unnamed: D1.A, PIN4.1
unnamed: IC2.8 (L), PIN1.1
unnamed: IC2.6 (K), PIN2.1, R1.1
unnamed: JP8.1, P1.P$1
RX: IC2.1 (RXK), JP5.1
TX: IC2.4 (TX), JP6.1
VCC: C2.+, C3.1, IC1.2 (OUT), IC2.3 (VDD), JP4.1

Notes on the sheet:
White/Yellow (+12V)
Red/Yellow (KBUS)
Black/Yellow (GND)
Gear Indicator (KBUS - KWP2000, ISO-14230) POWER SUPPLY
Brown (Red Pin)
Green (Green Pin)
White (Blue Pin)
Bike (KDS) socket
Green/Black
(Not used)
REED

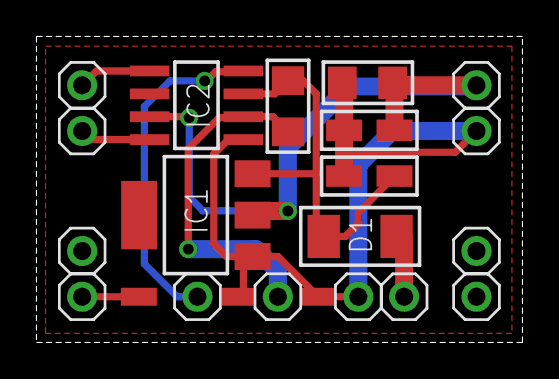
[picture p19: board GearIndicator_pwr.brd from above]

Board: 2 copper layers, 27.0 x 17.0 mm, 22 parts (0 on the bottom side), 9 nets.

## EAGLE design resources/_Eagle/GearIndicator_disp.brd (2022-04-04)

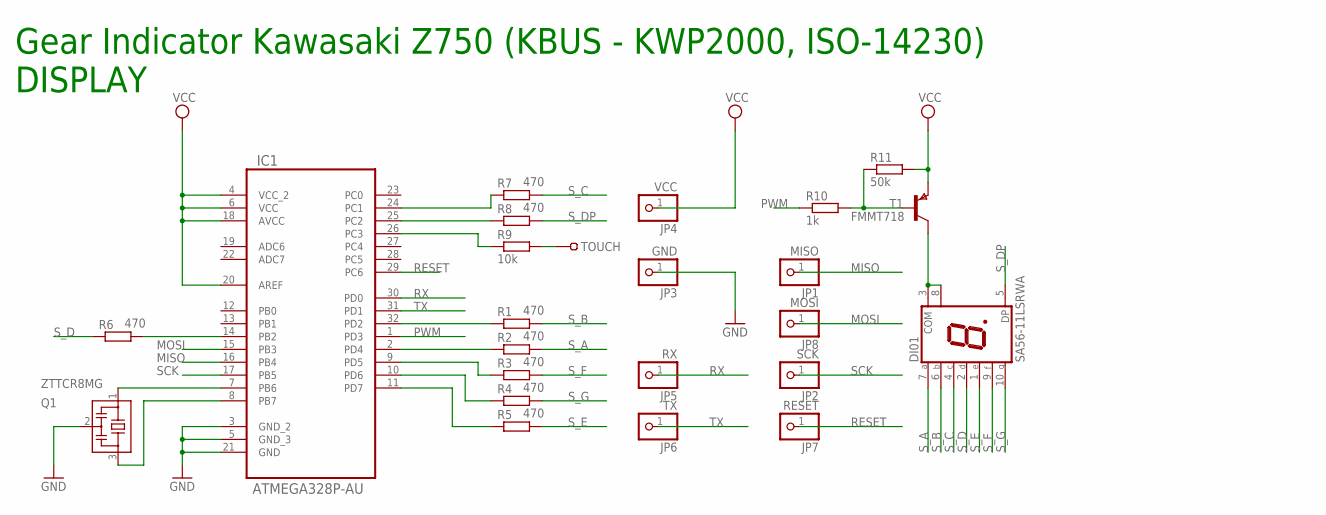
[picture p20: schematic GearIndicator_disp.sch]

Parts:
DI01: SA56-11LSRWA; SA56-11
IC1: ATMEGA328P-AU; QFP80P900X900X120-32N
JP1: MISO; PIN1
JP2: SCK; PIN1
JP3: GND; PIN1
JP4: VCC; PIN1
JP5: RX; PIN1
JP6: TX; PIN1
JP7: RESET; PIN1
JP8: MOSI; PIN1
Q1: ZTTCR8MG; ZTTCR
R1, R2, R3, R4, R5, R6, R7, R8: 470; R0603
R9: 10k; R0603
R10: 1k; R0603
R11: 50k; R0603
T1: FMMT718; SOT-23
TOUCH: SMD1; SMD_2X2

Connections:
GND: IC1.3 (GND_2), IC1.5 (GND_3), IC1.21 (GND), JP3.1, Q1.2
MISO: IC1.16 (PB4), JP1.1
MOSI: IC1.15 (PB3), JP8.1
unnamed: IC1.7 (PB6), Q1.1
unnamed: IC1.8 (PB7), Q1.3
unnamed: DI01.3 (COM), DI01.8 (COM), T1.1 (C)
unnamed: IC1.24 (PC1), R7.1
unnamed: IC1.25 (PC2), R8.1
unnamed: IC1.11 (PD7), R5.1
unnamed: IC1.14 (PB2), R6.1
unnamed: IC1.32 (PD2), R1.1
unnamed: IC1.2 (PD4), R2.1
unnamed: IC1.9 (PD5), R3.1
unnamed: R10.2, R11.1, T1.3 (B)
unnamed: IC1.26 (PC3), R9.1
unnamed: R9.2, TOUCH.P$1
unnamed: IC1.10 (PD6), R4.1
PWM: IC1.1 (PD3), R10.1
RESET: IC1.29 (PC6), JP7.1
RX: IC1.30 (PD0), JP5.1
SCK: IC1.17 (PB5), JP2.1
S_A: DI01.7 (A), R2.2
S_B: DI01.6 (B), R1.2
S_C: DI01.4 (C), R7.2
S_D: DI01.2 (D), R6.2
S_DP: DI01.5 (DP), R8.2
S_E: DI01.1 (E), R5.2
S_F: DI01.9 (F), R3.2
S_G: DI01.10 (G), R4.2
TX: IC1.31 (PD1), JP6.1
VCC: IC1.4 (VCC_2), IC1.6 (VCC), IC1.18 (AVCC), IC1.20 (AREF), JP4.1, R11.2, T1.2 (E)

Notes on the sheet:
Gear Indicator Kawasaki Z750 (KBUS - KWP2000, ISO-14230) DISPLAY

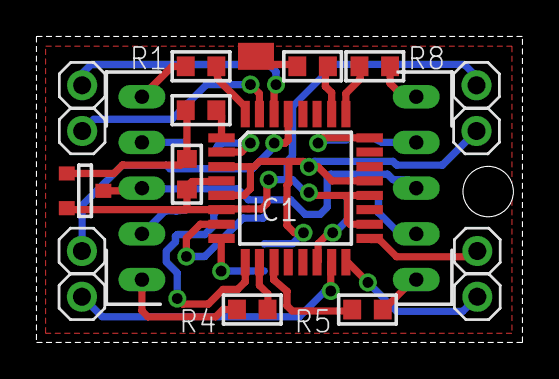
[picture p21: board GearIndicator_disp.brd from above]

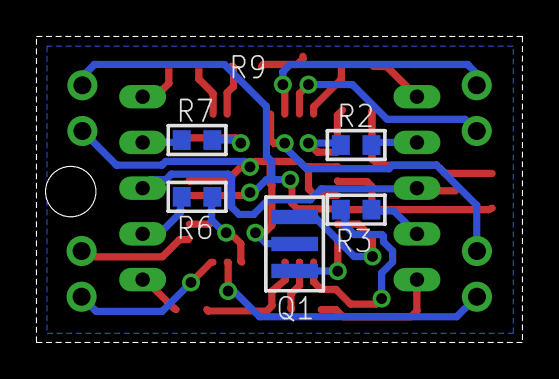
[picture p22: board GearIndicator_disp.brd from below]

Board: 2 copper layers, 27.0 x 17.0 mm, 24 parts (5 on the bottom side), 31 nets.

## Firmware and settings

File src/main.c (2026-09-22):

/*
 * main.c
 * Part of project: GearIndicator
 *
 * Gear indicator for Kawasaki (ECU address 11h) - tested with Z750, Versys, Z800,
 * and for Suzuki (ECU 12h) - tested with V-Strom, VL800,...
 * using KBUS communication to ECU via KDS (ISO-14230) protocol
 * Other bikes can be added, see bikes.c / bikes.h
 * Extra function: RPM over limit indication (display blinks fast if RMP are above set point value)
 *
 * Software developed in Atmel Studio (now Microchip Studio)
 * Controller:		ATmega328P
 * Hardware design: CadSoft Eagle (now Autodesk Eagle) - 2x 2 layers PCB, SMD design
 * 3D Modelling:	SketchUp
 *
 * Author: Andrej Hradnansky, 2022
 *
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
 * This program is distributed in the hope that it will be useful, but WITHOUT ANY WARRANTY;
 * without even the implied warranty of MERCHANTABILITY or FITNESS FOR A PARTICULAR PURPOSE.
 * See the GNU General Public License for more details.
 *
 * You should have received a copy of the GNU General Public License along with this program.
 * If not, see <https://www.gnu.org/licenses/>.
 */


#include "global.h"
#include <avr/io.h>
#include <util/delay.h>
#include <avr/interrupt.h>
#include <avr/wdt.h>
#include "uart.h"
#include "led.h"
#include "bikes.h"
#include "kbus.h"
#include "buffer.h"
#include "uart.h"
#include "timers.h"
#include "eeproma.h"

//RPM hysteresis for programming mode
//if actual RPM differs +/- this value, it is considered the same RPM
#define	 RPMHYSTERESYS	200							

int main(void)
{

//unsigned char *replymsgptr;
volatile unsigned char* replymsgptr;
volatile unsigned char actgear=10, newgear=10;
volatile unsigned int  actrpm=0, newrpm=2000;		//RPM value is 2 bytes long, so type is unsigned int
volatile unsigned char retries=1;
volatile unsigned char actualECU;					// actual ECU we currently communicate with
volatile unsigned char initcheck=YES;				// if COMM_REQ and DIAG_REQ reply from ECU is checked for its correctness
unsigned char replymsg[BUFF_LNG];
unsigned char f_prgmode=FALSE;
unsigned char f_exittmr_started=FALSE;

int i=0;											// temp variable i

	////////////////////////////////////////////////
	//Watch dog disable - in case it was enabled before
	wdt_disable();
	
	////////////////////////////////////////////////
	//LED display init
	LEDinit();					//display init

	////////////////////////////////////////////////
	//WELCOME MESSAGES
	//Uses direct LEDoutch() because timers don't run yet
	for(i=27;i<=35;i++)			//LEtS ridE
		{
			LEDoutch(i);
			_delay_ms(200);
			LEDclear();
			_delay_ms(200);
		}
		
	_delay_ms(400);
	
	//show display numbers - display test
	//and show '-' at the end
	for(i=0;i<=6;i++)
		{
			LEDoutch(i);
			_delay_ms(100);
		}
	
	for(i=6;i>0;i--)
		{
			LEDoutch(i);
			_delay_ms(100);
		}
	LEDoutch(0);
	_delay_ms(100);
	LEDoutch(10);			//display "-"
	
	//END OF WELCOME MESSAGES
	///////////////////////////////////////////////

	///////////////////////////////////////////////
	//Timers init
	TMRinit();
	
	//Read last used ECU from EEPROM
	EEPROMread();							//lastECU from EEPROM
	
	if(lastStatus.lastECU>NUM_OF_ECUS-1) 
		{
			lastStatus.lastECU=0;			//if lastECU is wrong number
			EEPROMwrite();					//write 0 to EEPROM
		}
	actualECU=lastStatus.lastECU;			//and set actualECU
	
	if(lastStatus.initcheck>1)
		{
			lastStatus.initcheck=YES;
			EEPROMwrite();
		}
	
	initcheck=lastStatus.initcheck;
	
	//RPM PROGRAMM MODE
	CLB(UARTDR,RX);			//RX is input
	STB(UARTPORT,RX);		//Pull up
	
	//if RX pin is LOW
	//Entering programming mode
	TIMER[PRGMODE]=PRGMODETMR;			//set the timer
	while(!(UARTPIN & (1<<RX)))			//if RX is LOW
		{
			sei();						//enable INT		
			if(!TIMER[PRGMODE])			//and timer expired	
				{
					displayedchar=36;	//display P - programming mode
					rpmValue.prgmode=0;	//store prgmode to EEPROM - prgmode active = 0
					rpmValue.rpm=0;		//store rpm
					EEPROM_rpm_write();	//to EEPROM		
					f_dispblink=TRUE;
					while(TRUE);		//wait until indicator is turned off/reset
				}
		}
	
	cli();								//disable INT
	
	///////////////////////////////////////////////
	//UART init
	UARTinit();
	
	///////////////////////////////////////////////
	//PROGRAMMING MODE
	EEPROM_rpm_read();					//get data from EEPROM
	
	//if EEPROM is empty 0xFFFF
	if(rpmValue.rpm==0xFFFF)			
		{
			rpmValue.rpm=0;				//Make it 0
			rpmValue.prgmode=0xFF;		//Programm mode off
			EEPROM_rpm_write();			//Store rpm to EEPROM
		}
		
	//if we are entering  prog mode
	if(rpmValue.prgmode==0)				
		{
			f_prgmode=TRUE;				//program mode active
			displayedchar=36;			//display P
		}
	
	///////////////////////////////////////////////
	//START ENDLESS LOOP
    while(TRUE)
		{	
			////////////////////////////////////////////
			//PROGRAMMING MODE EXIT - IN CASE NO RPM IS SET
			//start programing mode exit timer in the beginning
			if(f_prgmode && !f_exittmr_started)
				{
					f_exittmr_started=TRUE;
					TIMER[PGMEXIT]=PGMEXITTMR;
				}
			
			//if 	exit timer expired SET DEFAULT STATUS (without RPM indication set)
			if(!TIMER[PGMEXIT] && f_exittmr_started)
				{
					f_exittmr_started=FALSE;	
					rpmValue.rpm=0;
					rpmValue.prgmode=0xFF;
					EEPROM_rpm_write();
					f_prgmode=FALSE;
				}
			//PROGRAMMING MODE EXIT (END)
			///////////////////////////////////////////
			
			KBUS_send_msg(actualECU);			//Send K-Bus message
			
			if(	(initcheck==YES)||\
				(initcheck==NO && KBUS_state==KBUS_S_COMM_STARTED)||\
				(initcheck==NO && KBUS_state==KBUS_S_DATA_POOLING) )
				{
							
					TIMER[REPLY]=REPLYTMR;				//start timer - waiting for reply
												
					while(!(UCSR0B & (1<<RXEN0)));				//Wait until Receiver is enabled
			
					while(TIMER[REPLY] && !TIMER[RXFINISHED]);	//Wait until character is received or TIMER expires
			
					//If timer expired, try again
					if(!TIMER[REPLY]) 
						{
							if(retries<NOOFRETRIES)
								{
									retries++;
								}
							else
								{	
									//ECU does not reply 
									f_dispblink=FALSE;
									
									if(f_prgmode)
										displayedchar=36;	//in PROGRAMMING MODE display "P"
									else 
										displayedchar=10;	//else display "-"
										
									IO_CLR(DP_BIT);		    //Turn DP on the display as flag that ECU does not reply
							
									//lets see if we have another ECU connected
									//if we check reply for init commands, we will try not to
									if(initcheck==YES)
										{
											initcheck=NO;
										}
									else
									//if we don't check reply, try another ECU and check replies from init commands at first
									//try another known ECU
										{
											actualECU=(actualECU+1) % NUM_OF_ECUS;
											initcheck=YES;
										}
										
									//K-Bus state is idle - no reply until now
									KBUS_state = KBUS_S_IDLE;
									retries=1;
								}
						
							_delay_ms(200);					//time between queries should be 55-5000ms (ISO14230)
							continue;
						}

					while(TIMER[RXFINISHED]);				//wait while whole reply message has arrived
			
					//Clear the buffer
					for(i=0;i<BUFF_LNG;i++) replymsg[i]=BUFFFILLCHAR;
				
					i=0;
				
					while(BUFFpop(&rxbuf,&replymsg[i]))		//read all data from the RX buffer to replymsg
						{
							i=(i+1) % BUFF_LNG;
						}
				
					/////////////////////////////////////////////////
					//Check the message	
					//Find the beginning of the message in the buffer (if necessary) 
					for(i=0;i<BUFF_LNG-2;i++)
						{
							//reply starts 0x00 or 0x40	
							if((replymsg[i]&0xF0)==NO_ADDRESS||(replymsg[i]&0xF0)==CARB) break;
							
							//reply starts 0x80 or 0xC0
							if(((replymsg[i]&0xF0)==PHYSICAL_ADDR ||(replymsg[i]&0xF0)==FUNCTIONAL_ADDR) &&\
								replymsg[i+1]==IND_ADDR &&\
								replymsg[i+2]==BIKES_DATA[actualECU].ecu_addr)
									break;
						}
						
					//Start of the message was found	
					if(i!=BUFF_LNG-2)
						{
							replymsgptr=&replymsg[i];
						}
					//Start of the message was not found
					else
						{
							//?? Something wrong;
							//LEDoutch(16);			//display "E"rror
							displayedchar=16;
							continue;
						}
							
				
					//if reply is OK
					if(KBUS_check_reply(actualECU,replymsgptr))
						{
							//Store ECUno which is active to EEPROM, if necessary
							if(actualECU!=lastStatus.lastECU)
								{
									lastStatus.lastECU=actualECU;
									EEPROMwrite();
								}
								
							if(initcheck!=lastStatus.initcheck)
						
								{
									lastStatus.initcheck=initcheck;
									EEPROMwrite();
								}
							//If we are already getting data - display gear on the LED display and/or get RPM
							if(KBUS_state==KBUS_S_DATA_POOLING)
								{
									//GEAR
									if(*(replymsgptr+5)==BIKES_DATA[actualECU].local_id_gear)
									{
										newgear = *(replymsgptr+BIKES_DATA[actualECU].byte_no_gear);	//byte of the message where is the gear value stored
										if(newgear > 9) newgear = 10;									//Number >9 is displayed as "-"
										
										if(f_prgmode)
											displayedchar=36;											//always display P in program mode
										else
											{							
												if(newgear!=actgear)
												{
													//LEDoutch(newgear);		
													displayedchar=newgear;								//display gear
												
													actgear=newgear;
												}
											}
									}
									
									//RPM
									if(*(replymsgptr+5)==BIKES_DATA[actualECU].local_id_rpm)
									{
										switch(actualECU)
										{
											//KAWASAKI (Z750: rpm byte * 100;...)
											case 0:													
												actrpm=(unsigned int)*(replymsgptr+BIKES_DATA[actualECU].byte_no_rpm)*100;
												break;
										
											//SUZUKI (DL650: rpm byte * 62.5;...)
											case 1:
												actrpm=(unsigned int)*(replymsgptr+BIKES_DATA[actualECU].byte_no_rpm)*62.5;
												break;
											
											default:
												break;
										}
												
										
										//////////////////////////
										//PROGRAMM MODE - STORE RPM TO EEPROM
										
										
										if(f_prgmode) 
											{
												//if actrpm > 3000
												if(actrpm>3000)
													{	
														//restart PROGRAMING MODE EXIT timer
														TIMER[PGMEXIT]=PGMEXITTMR;
														
														//if  actrpm is out of hysteresis interval
														if(!(actrpm>newrpm-RPMHYSTERESYS && actrpm<newrpm+RPMHYSTERESYS))
															{
																//we have new RPM value
																newrpm=actrpm;
																//start the timer
																TIMER[VALACCEPT]=VALACCEPTTMR;
																f_dispblink=FALSE;
																
															}
														//actrpm is in hysteresis interval	
														else
															{	
																//timer has expired
																if(!TIMER[VALACCEPT])
																	{	
																		//store new RPM value to EEPROM
																		rpmValue.rpm=newrpm;
																		rpmValue.prgmode=0xFF;
																		EEPROM_rpm_write();
																		f_dispblink=TRUE;
																		//f_prgmode=FALSE;
																	}
															}
													}
													
												//actrpm<=3000
												else
													{
														//nothing to do here ??
													}
											}
										else
											//f_prgmode=FALSE
											{	
												if(actrpm>=rpmValue.rpm && rpmValue.rpm>0)
													f_dispblink=TRUE;
												else
													f_dispblink=FALSE;
											}
											
										//END OF RPM PROGRAMMING AND INDICATION
										///////////////////////////
									}
								}
						}
					//If reply is not ok
					else
						{
							//?? Reply is not OK
							//LEDoutch(16);		//display "E"rror
							displayedchar=16;
							continue;
						}
			
					retries=1;
					_delay_ms(100);	//time between queries should be 55-5000ms (ISO14230)
				}
			else
				{
					_delay_ms(300);
					if(KBUS_state==KBUS_S_IDLE)
						{
							KBUS_state=KBUS_S_COMM_STARTED;
							continue;
						}
				} 
		}
}

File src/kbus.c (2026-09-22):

/*
 * kbus.c
 * Part of project: GearIndicator
 * Created: 25.05.2015 8:54:04
 * Author: Andrej Hradnansky, 2022
 *
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
 * This program is distributed in the hope that it will be useful, but WITHOUT ANY WARRANTY;
 * without even the implied warranty of MERCHANTABILITY or FITNESS FOR A PARTICULAR PURPOSE.
 * See the GNU General Public License for more details.
 *
 * You should have received a copy of the GNU General Public License along with this program.
 * If not, see <https://www.gnu.org/licenses/>.
 */ 

#include "global.h"
#include <util/delay.h>
#include <avr/interrupt.h>
#include <avr/io.h>
#include <avr/wdt.h>
#include "uart.h"
#include "bikes.h"
#include "kbus.h"
#include "timers.h"
#include "eeproma.h"
#include <string.h>

//State of the K-Bus communication
tKBUS_state KBUS_state=KBUS_S_IDLE;		

////////////////////////////////////////////
//KBUS commands - partially :-)
////////////////////////////////////////////
//StartCommunication Request 
tKBUS_Msg KBUS_STC_req = {.form=ADDRESS_NO_LBYTE,					//Message with address without additional message length byte
						.header={
								.HForm_MsgLen=PHYSICAL_ADDR + 1,//Physical addressing + message  lenght (1 byte)
								.Tgt=0x11,						//Target address -> ECU address (0x11 - Kawa)
								.Src=IND_ADDR					//Source address = Indicator address
								},
						.data.Sld=STC,							//startCommunication Request Service Id
						.cs=0x04								//Check sum
						};


//Byte	Name				Value		Description
//-----------------------------------------------
//0		Fmt					0x81		Physical addressing PHYSICAL_ADDR<<6 + length of information (1 byte) = 0x81
//1		Tgt					<Ttg>		Address of target device (ECU)
//2		Src					IND_ADDR	Address of source device (GEAR INDICATOR)
//3		STC					0x81		startCommunication Request Service Id		
//4		CS					<CS>		Example: CHS = 04 = 81+11+F1+81 modulo 0x100 -> 0x81,0x11,0xF1,0x81,0x04
//			
////////////////////////////////////////////
//startCommunication Positive Response
unsigned char KeyBytes[2]={0xEA,0x8F};
	
tKBUS_Msg KBUS_STC_res = {.form=ADDRESS_LBYTE,					//Message with address and with extra length byte
						.header={
								.HForm_MsgLen=PHYSICAL_ADDR,	//Physical addressing
								.Tgt=IND_ADDR,					//Target address = Indicator address
								.Src=0x11,						//Source address = ECU
								.Len=3							//Data length - number of data bytes
								},
						.data.Sld=STCPR,						//startCommunication Positive Response Service Id
						.data.Data=KeyBytes,
						.cs=0xBF								//Check sum
						};

//Byte	Name				Value        Description
//------------------------------------------------------------------------------
//0		Fmt					0x80		Address mode: physical addressing + Len
//1		Tgt					IND_ADDR	Address of target devide (GEAR INDICATOR)
//2		Src					<ADDR>		Address of source device (ECU)
//3		Len					0x03		3 Bytes following...
//4		STCPR				0xC1		startCommunication Positive Response Service Id
//5		KB1					0xEA		Header with target and source address information
//6		KB2					0x8F		Additional length byte used
//7		CS					<CS>		Example: CHS BF = 80+F1+...+8F modulo 0x100 ->0x80,0x11,0x03,0xC1,0xEA,0x8F,0xBF
//
////////////////////////////////////////////	
//StartDiagnosticSession Request 
unsigned char KBUS_START_DIAG[7] =		{PHYSICAL_ADDR,0x11,IND_ADDR,0x02,SDS,0x80,0x14};	
	
unsigned char diagnosticMode=0x80;							//manufacterSpecific - 00-7F reserved, 80-FF for vehicle manufacturer specific use
tKBUS_Msg KBUS_SDS_req = {.form=ADDRESS_LBYTE,				//Message with address and with extra length byte
						.header={
							.HForm_MsgLen=PHYSICAL_ADDR,	//Physical addressing
							.Tgt=0x11,						//Target address -> ECU address (0x11 - Kawa)
							.Src=IND_ADDR,					//Source address = Indicator address
							.Len=2							//Data length - number of data bytes
							},
						.data.Sld=SDS,						//startDiagnosticSession Request Service Id
						.data.Data=&diagnosticMode,			//manufacterSpecific - 00-7F reserved, 80-FF for vehicle manufacturer specific use
						.cs=0x14							//Check sum
						};	
		
//Byte	Name				Value		 Description
//-------------------------------------------------------------------------------------
//0		Fmt					0x80		Address mode: physical addressing + Len
//1		Tgt					<ADDR>		Address of target device (ECU)
//2		Src					IND_ADDR	Address of source device (GEAR INDICATOR)
//3		Len					0x02		2 Bytes following...
//4		SDS					0x10		startDiagnosticSession Request Service Id
//5		diagnosticMode		0x80		manufacterSpecific - 00-7F reserved, 80-FF for vehicle manufacturer specific use
//6		CS					<CS>		Example: CHS = 14 = 80+11+F1+02+10+80 modulo 0x100 ->0x80,0x11,0xF1,0x02,0x10,0x80,0x14
//
////////////////////////////////////////////
//startDiagnosticSession Positive Response
unsigned char KBUS_START_DIAG_RPL[7] =	{PHYSICAL_ADDR,IND_ADDR,0x11,0x02,SDSPR,0x80,0x54};		
	
tKBUS_Msg KBUS_SDS_res = {.form=ADDRESS_LBYTE,				//Message with address and with extra length byte
						.header={
							.HForm_MsgLen=PHYSICAL_ADDR,	//Physical addressing
							.Tgt=IND_ADDR,					//Target address = indicator address
							.Src=0x11,						//Source address = ECU
							.Len=2							//Data length - number of data bytes
							},
						.data.Sld=SDSPR,					//startDiagnosticSession Request Service Id
						.data.Data=&diagnosticMode,			//manufacterSpecific - 00-7F reserved, 80-FF for vehicle manufacturer specific use
						.cs=0x54							//Check sum
						};	

//Byte	Name				Value		Description
//-----------------------------------------------------------------------------------
//0		Fmt					0x80		Address mode: physical addressing +Len
//1		Tgt					IND_ADDR	Address of target device (GEAR INDICATOR)
//2		Src					<ADDR>		Address of source device (ECU)
//3		Len					0x02		2 Bytes following...
//4		SDSPR				0x50		startDiagnosticSession Positive Response Service Id
//5		Diagnostic mode		0x80		manufacterSpecific
//6		Checksum			<CS>		Example: CS = 54 ->0x80,0xF1,0x11,0x02,0x50,0x80,0x54
//
////////////////////////////////////////////
//readDataByLocalIdentifier Request
unsigned char KBUS_READ_DATA[7]  =		{PHYSICAL_ADDR,0x11,IND_ADDR,0x02,RDBLID,0x0B,0xB0};

unsigned char RLOCID=0xB0;
tKBUS_Msg KBUS_RDBLID_req = {.form=ADDRESS_LBYTE,				//Message with address and with extra length byte
							.header={
								.HForm_MsgLen=PHYSICAL_ADDR,	//Physical addressing
								.Tgt=0x11,						//Target address = ECU
								.Src=IND_ADDR,					//Source address = Indicator address
								.Len=2							//Data length - number of data bytes
								},
							.data.Sld=RDBLID,					//readDataByLocalIdentifier Request Service Id
							.data.Data=&RLOCID,					//recordLocalIdentifier (to be read)
							.cs=0xB0							//Check sum	
							};
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

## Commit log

2022-04-04 Master commit
    [GearIndicator_disp.brd, GearIndicator_disp.sch, GearIndicator_pcb.skp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]
2026-09-22 Updated docs, transfeterd to PlatformIO
    [GearIndicator_disp.brd, GearIndicator_disp.sch, GearIndicator_pcb.skp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]
2026-09-22 Cleaned docs and added version print and .hex and .elf files output after successful compile

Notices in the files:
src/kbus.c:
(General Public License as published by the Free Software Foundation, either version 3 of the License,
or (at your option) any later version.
